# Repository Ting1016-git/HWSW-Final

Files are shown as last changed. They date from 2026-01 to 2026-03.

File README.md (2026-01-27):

# Smart Kitchen Guide

## Project Overview

**Smart Kitchen Guide** is a two-device cooking assistance system designed to help beginners master temperature control in cooking - from Chinese stir-frying to Western pan-searing. The system consists of a **Smart Handle Clip (Sensing Device)** that clamps onto any pan handle and monitors temperatures using triple sensing technology, and a **Cooking Terminal (Display Device)** that provides visual feedback through a stepper motor-driven gauge, LED indicators, and recipe guidance.

The sensing device wirelessly transmits temperature data to the display device, which uses a predictive algorithm to estimate when the target temperature will be reached and alerts the user at the optimal moment to add ingredients.

### Key Features

- **Triple Temperature Sensing**: Pan surface (IR), oil temperature (IR), and food internal temperature (K-type probe)
- **Universal Compatibility**: Spring-clip design fits handles from 15-40mm diameter
- **Open-Pan Cooking**: Perfect for stir-frying and sautéing without blocking the view
- **Wireless BLE Communication**: Real-time data transmission at 10Hz

### General Sketch

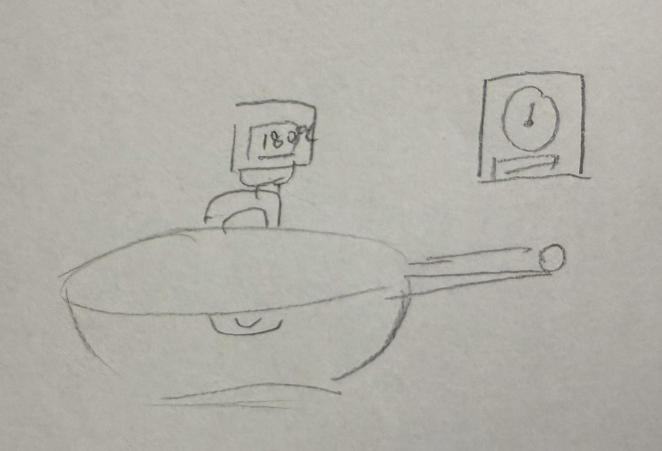
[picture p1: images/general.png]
General System Sketch


**Physical Features:**
- **Smart Handle Clip**: Spring-loaded clamp with OLED display, IR temperature sensor pointing toward pan body, detachable K-type thermocouple probe, and USB-C rechargeable battery
- **Cooking Terminal**: Retro radio-style desktop unit featuring a large circular temperature gauge with stepper motor-driven needle, RGB LED ring, OLED recipe display, and three tactile buttons (Select/Confirm/Back)

---

## Sensing Device: Smart Handle Clip

### Device Description

The Smart Handle Clip is a portable, clip-on temperature monitoring device that attaches to any pan or wok handle. It features **triple temperature sensing capability**:

1. **Infrared (IR) Sensor** - Non-contact measurement of pan surface and oil temperature
2. **K-Type Thermocouple Probe** - Detachable probe for measuring food internal temperature

The clip-on design allows the pan to remain open during cooking, making it ideal for Chinese stir-frying and Western sautéing where visual monitoring is essential.

### Detailed Sketch

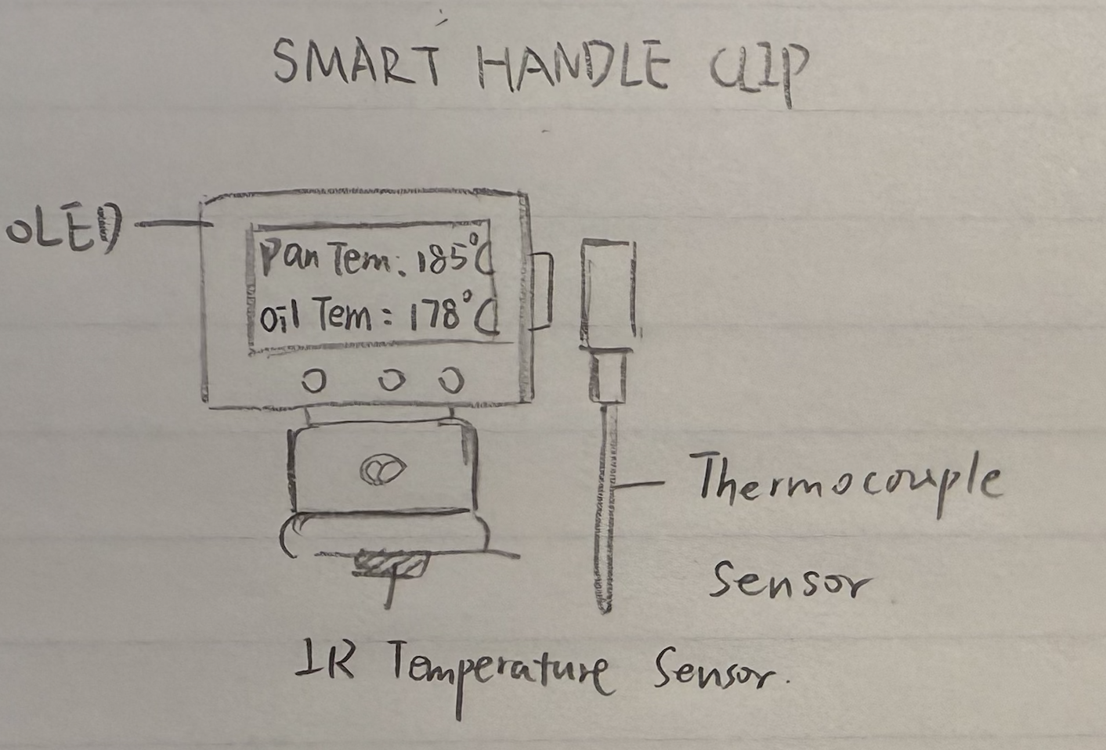
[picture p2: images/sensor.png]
Smart Handle Clip Detailed Sketch


### How It Works

1. **MLX90614 IR sensor** (mounted on bottom jaw, pointing toward pan) measures pan surface temperature from -70°C to +380°C without contact
2. The same IR sensor can measure **oil surface temperature** when the user aims it at the oil (mode switchable via button)
3. **Detachable K-type thermocouple probe** connects via port on the side for measuring food internal temperature (e.g., checking if meat is cooked through)
4. **MAX31855** thermocouple amplifier digitizes the probe signal via SPI
5. **ESP32-C3** microcontroller processes all sensor data at 10Hz and transmits via BLE
6. **0.96" OLED display** shows real-time temperature readings locally
7. **3 Status LEDs** indicate: Green (ready), Yellow (heating), Red (warning/overheat)
8. **500mAh Li-Po battery** provides ~8 hours of operation with USB-C charging

### Components & Part Numbers

| Component | Part Number | Description |
|---|---|---|
| Microcontroller | **ESP32-C3-MINI-1** | WiFi/BLE MCU, low power, SPI/I2C support |
| IR Temperature Sensor | **MLX90614ESF-BAA** | Non-contact IR thermometer, -70°C to +380°C, I2C |
| Thermocouple Sensor | **K-Type Thermocouple Probe** | Detachable, -50°C to +300°C, food-grade stainless steel |
| Thermocouple Amplifier | **MAX31855KASA+T** | Cold-junction compensated, SPI interface |
| OLED Display | **SSD1306 0.96" 128x64** | I2C interface, low power |
| Status LEDs | **0603 SMD LED** | Green, Yellow, Red (x3) |
| Battery | **Li-Po 502535** | 3.7V 500mAh rechargeable |
| Voltage Regulator | **AP2112K-3.3** | 3.3V LDO, 600mA output |
| Charging IC | **TP4056** | 1A Linear Li-ion charger, USB-C |
| Buttons | **TS-1109S** | 6x6mm SMD tact switch (x2: Power, Mode) |

## Display Device: Cooking Terminal

### Device Description

The Cooking Terminal is a desktop unit that receives temperature data from the Smart Handle Clip and provides rich visual feedback. The centerpiece is a large analog-style gauge with a stepper motor-driven needle showing current temperature. An RGB LED ring around the gauge indicates cooking status (heating/ready/overheating), while an OLED screen displays recipe steps and timing information. Users interact via three tactile buttons and can navigate through pre-loaded recipes.

### Detailed Sketch

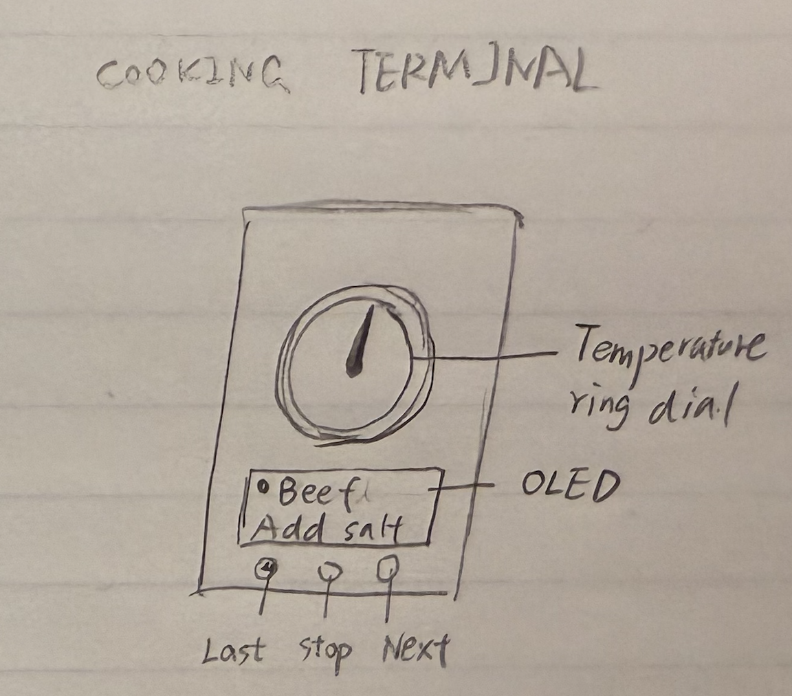
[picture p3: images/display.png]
Cooking Terminal Detailed Sketch


### How It Works

1. The **ESP32-S3** receives temperature data via BLE from the Smart Handle Clip
2. Temperature prediction algorithm estimates time-to-target based on heating rate
3. The **28BYJ-48 stepper motor** drives the gauge needle to indicate current temperature (0-300°C scale)
4. **WS2812B RGB LED ring** shows status: blue (cold), green (heating), amber (target reached), red (overheating)
5. **1.3" OLED display** shows recipe name, current step, target temperature, and countdown timer
6. Three **tactile buttons** allow navigation: Select (◀), Confirm (✓), Back (↩)
7. **Buzzer** provides audio alerts when target temperature is reached
8. Powered by **18650 Li-ion battery** with USB-C charging

### Components & Part Numbers

| Component | Part Number | Description |
|---|---|---|
| Microcontroller | **ESP32-S3-WROOM-1** | Dual-core, BLE 5.0, sufficient GPIO |
| Stepper Motor | **28BYJ-48** | 5V unipolar, 64:1 gear ratio |
| Stepper Driver | **ULN2003A** | Darlington array driver |
| RGB LED Ring | **WS2812B 16-LED Ring** | Addressable RGB, 5V |
| OLED Display | **SH1106 1.3" 128x64** | I2C interface |
| Tactile Buttons | **TS-1109S** | 6x6mm SMD tact switch (x3) |
| Buzzer | **MLT-5020** | 5V active buzzer |
| Battery | **NCR18650B** | 3.7V 3400mAh Li-ion |
| Battery Charger | **TP4056 Module** | USB-C Li-ion charger with protection |
| Voltage Regulator | **AMS1117-3.3** | 3.3V LDO for logic |
| 5V Boost | **MT3608** | Step-up converter for motor/LED |

## System Communication & Architecture

### Communication Diagram

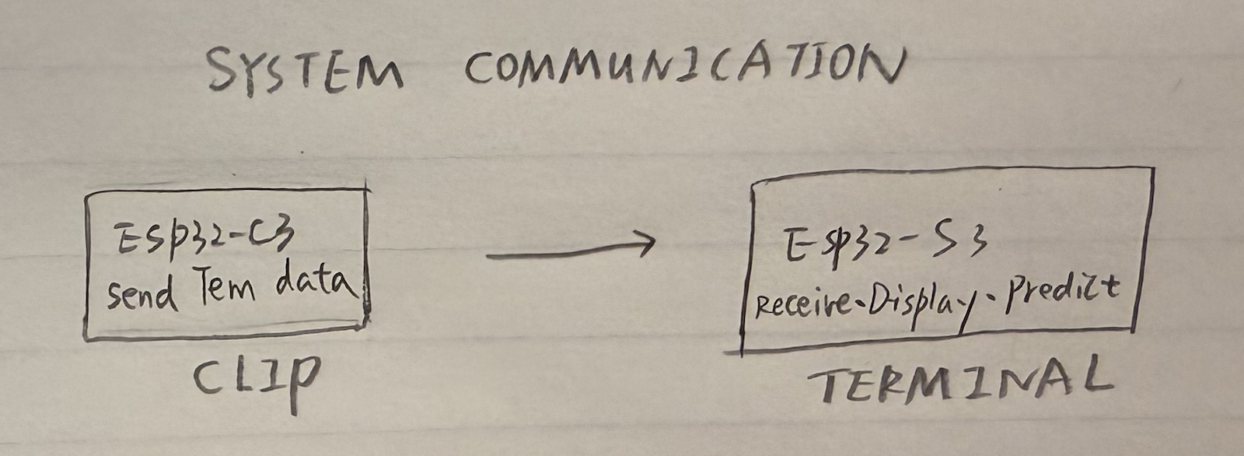
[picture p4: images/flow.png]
Communication Diagram


The Smart Handle Clip and Cooking Terminal communicate via **Bluetooth Low Energy (BLE)**:

- **Protocol**: BLE 5.0 with custom GATT service
- **Update Rate**: 10 Hz (100ms intervals)
- **Range**: Up to 10 meters (typical kitchen environment)
- **Latency**: < 50ms end-to-end

### System Block Diagram

```
┌─────────────────────────────────────────────────────────────────────────────────────┐
│                                 SYSTEM OVERVIEW                                     │
│                                                                                     │
│                                                                                     │
│    ┌──────────────────────┐                         ┌──────────────────────┐        │
│    │                      │                         │                      │        │
│    │   SENSING DEVICE     │      BLE 5.0 Link       │   DISPLAY DEVICE     │        │
│    │  (Smart Handle Clip) │ ═══════════════════════►│  (Cooking Terminal)  │        │
│    │                      │      10Hz, <50ms        │                      │        │
│    │                      │                         │                      │        │
│    └──────────────────────┘                         └──────────────────────┘        │
│                                                                                     │
│                                                                                     │
└─────────────────────────────────────────────────────────────────────────────────────┘
```

---

## Sensing Device (Smart Handle Clip)

```
┌─────────────────────────────────────────────────────────────────────────────────────┐
│                        SMART HANDLE CLIP (Sensing Device)                           │
│                                                                                     │
│                                                                                     │
│    ┌──────────────┐                             ┌──────────────┐                    │
│    │  MLX90614    │                             │ Xiao         │                    │
│    │  IR Sensor   ├──────────────┐      ┌───────┤ ESP32-C3     │                    │
│    │  (I2C)       │              │      │       │ (BLE TX)     │                    │
│    └──────────────┘              │      │       └───────┬──────┘                    │
│                                  │      │               │                           │
│                                  ▼      ▼               │                           │
│                              ┌──────────────┐           │          BLE 5.0          │
│                              │              │           │         ════════►         │
│                              │  Processing  │◄──────────┘                           │
│                              │              │                                       │
│                              └──────┬───────┘                                       │
│                                     │                                               │
│                           ┌─────────┴─────────┐                                     │
│                           │                   │                                     │
│                           ▼                   ▼                                     │
│                    ┌──────────────┐    ┌──────────────┐                             │
│                    │  WS2812B     │    │   Rotary     │                             │
│                    │  RGB LED     │    │   Encoder    │                             │
│                    │  (x1)        │    │   (EC11)     │                             │
│                    └──────────────┘    └──────────────┘                             │
│                                                                                     │
│                                                                                     │
│    ┌──────────────┐         ┌──────────────────────────────────────┐                │
│    │  Li-Po       │         │      Xiao ESP32-C3 Built-in          │                │
│    │  500mAh      ├────────►│  ┌────────────┐    ┌────────────┐    │                │
│    │  3.7V        │         │  │  TP4056    │    │   3.3V     │    │                │
│    └──────────────┘         │  │  Charger   │    │   LDO      │    │                │
│           ▲                 │  └──────┬─────┘    └──────┬─────┘    │                │
│           │                 │         │                 │          │                │
│       USB-C ────────────────┼─────────┘                 └──────────┼───► 3.3V       │
│                             │                                      │                │
│                             └──────────────────────────────────────┘                │
│                                                                                     │
│                                                                                     │
└─────────────────────────────────────────────────────────────────────────────────────┘
```

---

## Display Device (Cooking Terminal)

```
┌─────────────────────────────────────────────────────────────────────────────────────┐
│                        COOKING TERMINAL (Display Device)                            │
│                                                                                     │
│                                              │                                      │
│                                              │ BLE 5.0                              │
│                                              ▼                                      │
│                                      ┌──────────────┐                               │
│                              ┌───────┤ Xiao         │                               │
│                              │       │ ESP32-C3     ├───────┐                       │
│                              │       │ (BLE RX)     │       │                       │
│                              │       └──────────────┘       │                       │
│                              │               │              │                       │
│                              │               │              │                       │
│      ┌───────────────────────┼───────────────┼──────────────┼───────────────┐       │
│      │                       │               │              │               │       │
│      ▼                       ▼               ▼              ▼               ▼       │
│ ┌──────────┐ ┌──────────┐ ┌──────────┐ ┌──────────┐ ┌──────────┐ ┌──────────┐       │
│ │ ULN2003A │ │ WS2812B  │ │ SH1106   │ │ Rotary   │ │ Piezo    │ │ Temp     │       │
│ │ Driver   │ │ RGB Ring │ │ OLED     │ │ Encoder  │ │ Buzzer   │ │ Predict  │       │
│ │          │ │ (x8)     │ │ 1.3"     │ │ (EC11)   │ │          │ │ Algo     │       │
│ └────┬─────┘ └──────────┘ └──────────┘ └──────────┘ └──────────┘ └──────────┘       │
│      │                                                                              │
│      ▼                                                                              │
│ ┌──────────┐                                                                        │
│ │ 28BYJ-48 │                                                                        │
│ │ Stepper  │                                                                        │
│ │ Motor    │                                                                        │
│ └────┬─────┘                                                                        │
│      │                                                                              │
│      ▼                                                                              │
│ ┌──────────┐                                                                        │
│ │ Gauge    │                                                                        │
│ │ Needle   │                                                                        │
│ └──────────┘                                                                        │
│                                                                                     │
│                                                                                     │
│    ┌──────────────┐       ┌──────────────┐                                          │
│    │  18650       │       │   TP4056     │◄──── USB-C                               │
│    │  Battery     ├──────►│   Charger    │                                          │
│    │  3400mAh     │       │   (Xiao)     │                                          │
│    └──────────────┘       └───────┬──────┘                                          │
│                                   │                                                 │
│                    ┌──────────────┴──────────────┐                                  │
│                    │                             │                                  │
│                    ▼                             ▼                                  │
│            ┌──────────────┐             ┌──────────────┐                            │
│            │  Xiao 3.3V   │             │   MT3608     │                            │
│            │  LDO         │             │   Boost      │                            │
│            └───────┬──────┘             └───────┬──────┘                            │
│                    │                            │                                   │
│                    ▼                            ▼                                   │
│              3.3V (Logic)                 5V (Motor/LED)                            │
│              • Xiao MCU                   • ULN2003A                                │
│              • SH1106 OLED                • 28BYJ-48                                │
│              • Rotary Encoder             • WS2812B                                 │
│                                           • Piezo Buzzer                            │
│                                                                                     │
└─────────────────────────────────────────────────────────────────────────────────────┘
```

---

## Complete System Block Diagram

```
┌─────────────────────────────────────────────────────────────────────────────────────┐
│                        SMART HANDLE CLIP (Sensing Device)                           │
│                                                                                     │
│    ┌──────────────┐              ┌──────────────┐        ┌──────────────┐           │
│    │  MLX90614    │    I2C       │              │        │  WS2812B     │           │
│    │  IR Sensor   ├─────────────►│ Xiao         │◄───────┤  RGB LED     │           │
│    └──────────────┘              │ ESP32-C3     │        │  (x1)        │           │
│                                  │              │        └──────────────┘           │
│    ┌──────────────┐    GPIO      │ (BLE TX)     │        ┌──────────────┐           │
│    │  Rotary      ├─────────────►│              │        │  Li-Po       │           │
│    │  Encoder     │              └───────┬──────┘        │  500mAh      │           │
│    └──────────────┘                      │               └───────┬──────┘           │
│                                          │                       │                  │
│                                          │ BLE 5.0               │ Power            │
│                                          │                       ▼                  │
│                                          │               ┌──────────────┐           │
│                                          │               │ Xiao Built-in│           │
│                                          │               │ Charger+LDO  │◄── USB-C  │
│                                          │               └──────────────┘           │
│                                          │                       │                  │
│                                          │                       ▼                  │
│                                          │                    3.3V Out              │
└──────────────────────────────────────────┼──────────────────────────────────────────┘
                                           │
                                           │
                        ═══════════════════╪═══════════════════
                              Wireless     │     Communication
                        ═══════════════════╪═══════════════════
                                           │
                                           │
┌──────────────────────────────────────────┼──────────────────────────────────────────┐
│                        COOKING TERMINAL (Display Device)                            │
│                                          │                                          │
│                                          ▼                                          │
│    ┌──────────────────────────────────────────────────────────────────────────┐     │
│    │                            Xiao ESP32-C3                                 │     │
│    │                              (BLE RX)                                    │     │
│    │                                                                          │     │
│    │    ┌──────────────┐                                                      │     │
│    │    │    Temp      │                                                      │     │
│    │    │   Predict    │                                                      │     │
│    │    │    Algo      │                                                      │     │
│    │    └──────────────┘                                                      │     │
│    │                                                                          │     │
│    └───┬────────┬────────┬────────┬────────┬────────┬─────────────────────────┘     │
│        │        │        │        │        │        │                               │
│        ▼        ▼        ▼        ▼        ▼        ▼                               │
│   ┌────────┐┌────────┐┌────────┐┌────────┐┌────────┐┌────────┐                      │
│   │ULN2003A││WS2812B ││SH1106  ││Rotary  ││Piezo   ││        │                      │
│   │ Driver ││RGB Ring││OLED    ││Encoder ││Buzzer  ││        │                      │
│   └───┬────┘│ (x8)   ││ 1.3"   │└────────┘└────────┘│        │                      │
│       │     └────────┘└────────┘                    │        │                      │
│       ▼                                             │        │                      │
│   ┌────────┐                                        │        │                      │
│   │28BYJ-48│                                        │        │                      │
│   │Stepper │                                        │        │                      │
│   │ Motor  │                                        │        │                      │
│   └───┬────┘                                        │        │                      │
│       │                                             │        │                      │
│       ▼                                             │        │                      │
│   ┌────────┐                                        │        │                      │
│   │ Gauge  │                                        │        │                      │
│   │ Needle │                                        │        │                      │
│   └────────┘                                        │        │                      │
│                                                     │        │                      │
│                                                     │        │                      │
│    ┌──────────────┐      ┌──────────────┐           │        │                      │
│    │   18650      │      │   Xiao       │◄── USB-C  │        │                      │
│    │   Battery    ├─────►│   Charger    │           │        │                      │
│    │   3400mAh    │      └───────┬──────┘           │        │                      │
│    └──────────────┘              │                  │        │                      │
│                                  │                  │        │                      │
│                    ┌─────────────┴─────────────┐    │        │                      │
│                    │                           │    │        │                      │
│                    ▼                           ▼    │        │                      │
│            ┌──────────────┐            ┌──────────────┐      │                      │
│            │    3.3V      │            │   MT3608     │      │                      │
│            │    LDO       │            │   5V Boost   │      │                      │
│            └───────┬──────┘            └───────┬──────┘      │                      │
│                    │                           │             │                      │
│                    ▼                           ▼             │                      │
│               3.3V (Logic)                5V (Motor/LED)     │                      │
│                                                              │                      │
└─────────────────────────────────────────────────────────────────────────────────────┘
```

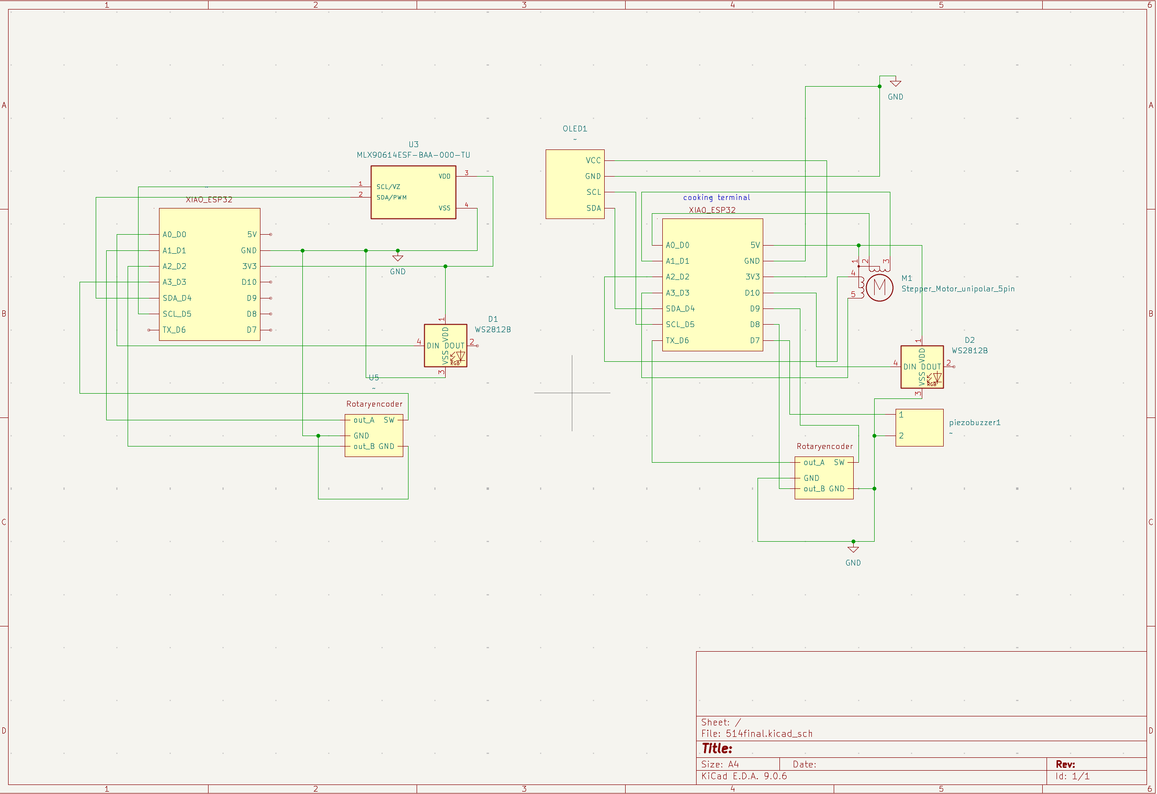
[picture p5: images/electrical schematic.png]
electrical schematic


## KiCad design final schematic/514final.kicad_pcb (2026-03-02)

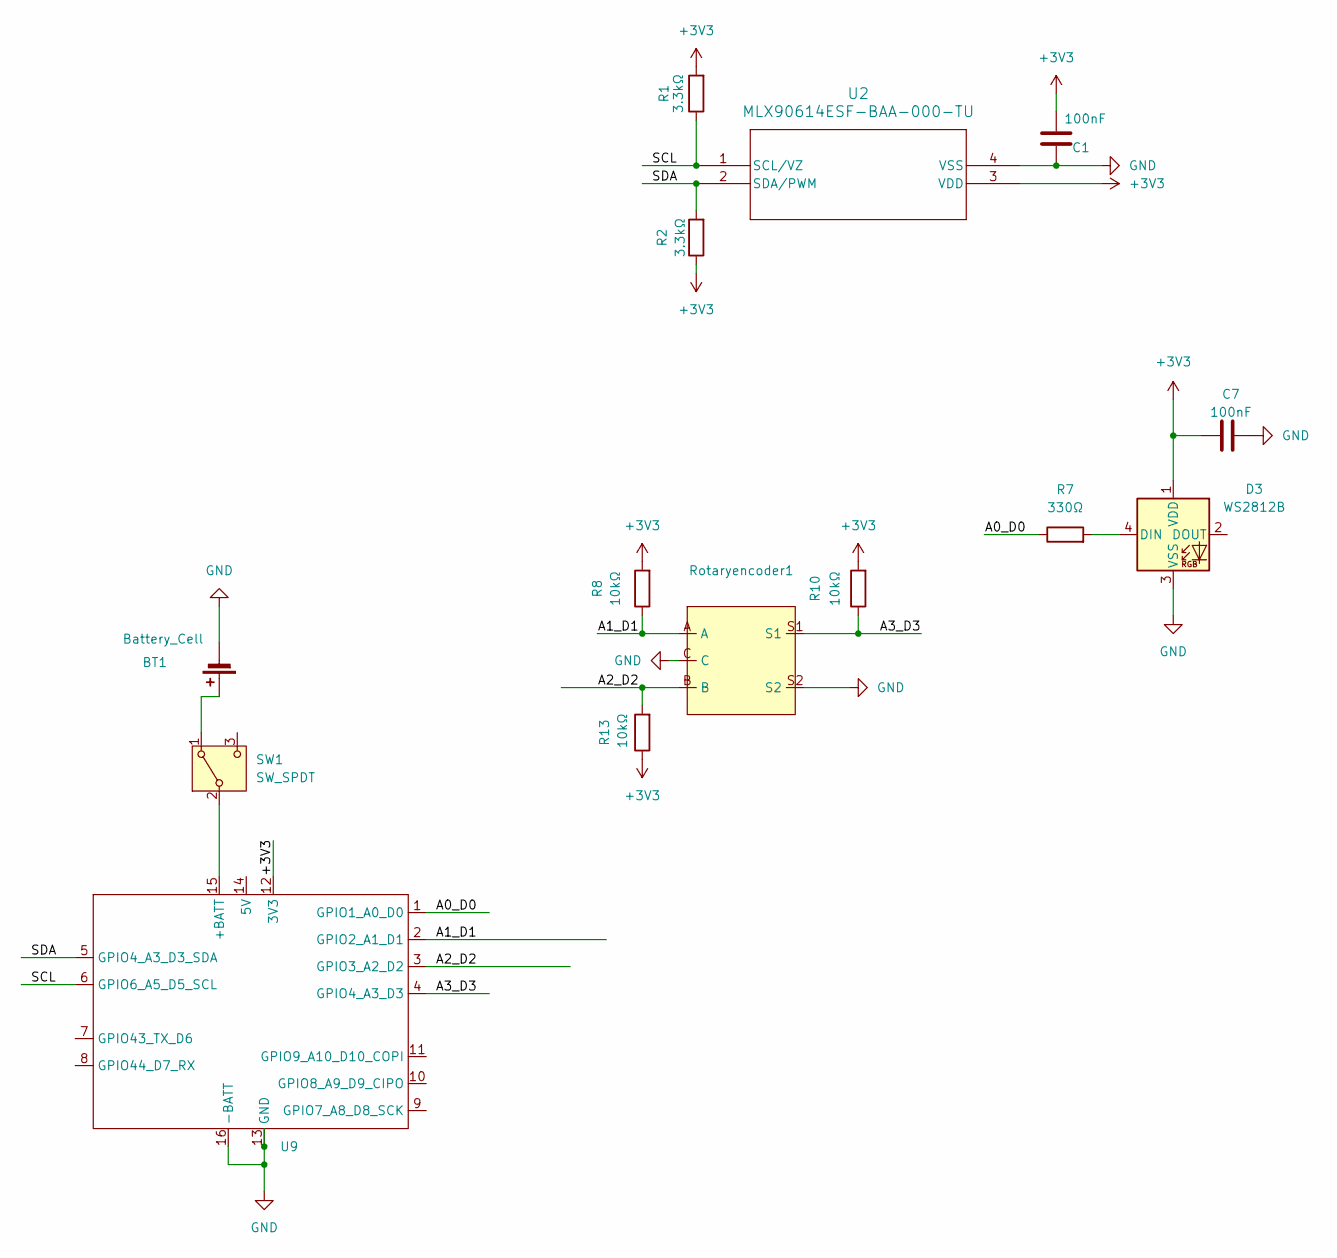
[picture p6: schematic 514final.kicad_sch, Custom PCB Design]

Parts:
BT1: Battery_Cell; PinSocket_1x02_P2.54mm_Vertical
C1, C7: 100nF; C_0603_1608Metric_Pad1.08x0.95mm_HandSolder
D3: WS2812B; LED_WS2812B_PLCC4_5.0x5.0mm_P3.2mm
R1, R2: 3.3kΩ; R_0603_1608Metric_Pad0.98x0.95mm_HandSolder
R7: 330Ω; R_0603_1608Metric_Pad0.98x0.95mm_HandSolder
R8, R10, R13: 10kΩ; R_0603_1608Metric_Pad0.98x0.95mm_HandSolder
Rotaryencoder1: RotaryEncoder_Alps_EC11E-Switch_Vertical_H20mm_CircularMoun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
SW1: SW_SPDT; PinSocket_1x03_P2.54mm_Vertical
U2: MLX90614ESF-BAA-000-TU; MLX90614ESF-BAA_MEL
U9: XIAO_ESP32

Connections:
+3V3: C1.1, C7.1, D3.1 (VDD), R1.2, R2.1, R8.2, R10.2, R13.1, U2.3 (VDD), U9.12 (3V3)
/A0_D0: R7.1, U9.1 (GPIO1_A0_D0)
/A1_D1: R8.1, Rotaryencoder1.A, U9.2 (GPIO2_A1_D1)
/A2_D2: R13.2, Rotaryencoder1.B, U9.3 (GPIO3_A2_D2)
/A3_D3: R10.1, Rotaryencoder1.S1, U9.4 (GPIO4_A3_D3)
/SCL: R1.1, U2.1 (SCL/VZ), U9.6 (GPIO6_A5_D5_SCL)
/SDA: R2.2, U2.2 (SDA/PWM), U9.5 (GPIO4_A3_D3_SDA)
GND: BT1.2 (-), C1.2, C7.2, D3.3 (VSS), Rotaryencoder1.C, Rotaryencoder1.S2, U2.4 (VSS), U9.13 (GND), U9.16 (-BATT)
unnamed: BT1.1 (+), SW1.1 (A)
unnamed: D3.4 (DIN), R7.2
unnamed: SW1.2 (B), U9.15 (+BATT)

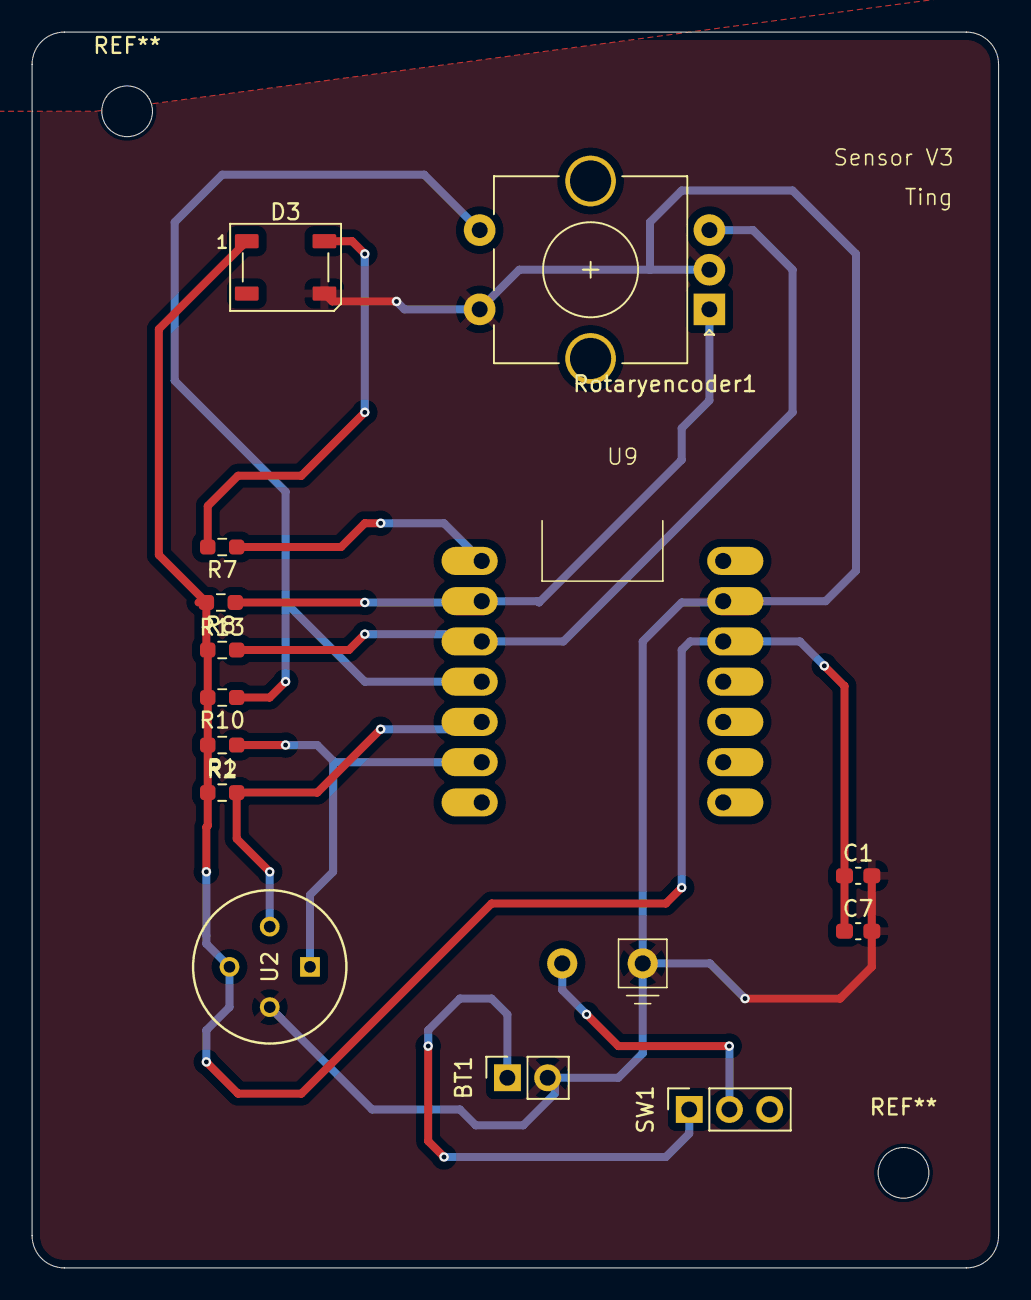
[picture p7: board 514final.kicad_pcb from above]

Board: 2 copper layers, 61.0 x 78.0 mm, 14 parts (0 on the bottom side), 11 nets.

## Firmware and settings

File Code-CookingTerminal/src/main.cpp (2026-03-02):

/*
 * Cooking Terminal - Smart Kitchen Guide
 * Version: 2.0 (Fixed & Complete)
 * 
 * Hardware:
 * - Xiao ESP32-C3 (Main MCU)
 * - SH1106 OLED 1.3" (I2C)
 * - X27.168 Stepper Motor (4-pin, direct GPIO)
 * - WS2812B RGB LED (1 LED)
 * - EC11 Rotary Encoder (5-pin)
 * - Piezo Buzzer (2-pin)
 * 
 * Pin Assignment:
 * - D0  (GPIO2)  -> X27.168 Pin 1 (Coil A+)
 * - D1  (GPIO3)  -> X27.168 Pin 2 (Coil A-)
 * - D2  (GPIO4)  -> X27.168 Pin 3 (Coil B+)
 * - D3  (GPIO5)  -> WS2812B DIN
 * - D4  (GPIO6)  -> OLED SDA
 * - D5  (GPIO7)  -> OLED SCL
 * - D6  (GPIO21) -> Encoder OUT_A
 * - D7  (GPIO20) -> Buzzer (+)
 * - D8  (GPIO8)  -> Encoder OUT_B
 * - D9  (GPIO9)  -> Encoder SW
 * - D10 (GPIO10) -> X27.168 Pin 4 (Coil B-)
 * 
 * Features:
 * - Temperature gauge display (0-300°C)
 * - OLED display with current/target temp
 * - Rotary encoder for target temp adjustment
 * - LED color status indicator
 * - Buzzer alerts when target reached
 */

#include <Arduino.h>
#include <Wire.h>
#include <Adafruit_GFX.h>
#include <Adafruit_SH110X.h>
#include <Adafruit_NeoPixel.h>

// ============== Pin Definitions ==============
// X27.168 Stepper Motor (4-pin)
#define STEPPER_PIN1  2    // D0 - GPIO2 - Coil A+
#define STEPPER_PIN2  3    // D1 - GPIO3 - Coil A-
#define STEPPER_PIN3  4    // D2 - GPIO4 - Coil B+
#define STEPPER_PIN4  10   // D10 - GPIO10 - Coil B-

// WS2812B LED
#define LED_PIN       5    // D3 - GPIO5
#define LED_COUNT     1

// OLED Display (I2C)
#define OLED_SDA      6    // D4 - GPIO6
#define OLED_SCL      7    // D5 - GPIO7

// Rotary Encoder
#define ENCODER_A     21   // D6 - GPIO21
#define ENCODER_B     8    // D8 - GPIO8
#define ENCODER_SW    9    // D9 - GPIO9

// Buzzer
#define BUZZER_PIN    20   // D7 - GPIO20

// ============== Objects ==============
Adafruit_SH1106G oled(128, 64, &Wire, -1);
Adafruit_NeoPixel led(LED_COUNT, LED_PIN, NEO_GRB + NEO_KHZ800);

// ============== Function Prototypes ==============
void stepMotor(int step);
void homeStepper();
void updateStepper();
void readEncoder();
void checkButton();
void simulateTemperature();
void updateLED();
void beep(int duration);
void alertBeep();
void updateDisplay();
void checkTargetReached();

// ============== Variables ==============
// Stepper motor
int currentStep = 0;
int targetStep = 0;
const int STEPS_PER_REV = 600;    // X27.168 steps per revolution
const int MAX_STEPS = 450;         // 270 degrees (3/4 of 600)
unsigned long lastStepTime = 0;
const int STEP_DELAY_US = 1500;    // Microseconds between steps

// Encoder
volatile int encoderPos = 0;
int lastEncoderA = HIGH;
int lastEncoderB = HIGH;
bool buttonPressed = false;
unsigned long lastButtonTime = 0;
const int DEBOUNCE_DELAY = 200;

// Temperature
float currentTemp = 25.0;          // Current measured temperature
float targetTemp = 150.0;          // User-set target temperature
bool targetReached = false;        // Flag for target reached alert
bool alertPlayed = false;          // Flag to prevent repeated alerts

// Display update
unsigned long lastDisplayUpdate = 0;
const int DISPLAY_UPDATE_INTERVAL = 100;  // ms

// Stepper sequence for X27.168 (modified for correct rotation)
const int stepSequence[4][4] = {
  {1, 0, 0, 1},  // Step 0
  {1, 0, 1, 0},  // Step 1
  {0, 1, 1, 0},  // Step 2
  {0, 1, 0, 1}   // Step 3
};

// ============== Setup ==============
void setup() {
  Serial.begin(115200);
  delay(1000);
  Serial.println("\n================================");
  Serial.println("Cooking Terminal v2.0 Starting...");
  Serial.println("================================\n");

  // Initialize I2C for OLED
  Wire.begin(OLED_SDA, OLED_SCL);
  Serial.println("[INIT] I2C initialized");
  
  // Initialize OLED
  Serial.print("[INIT] OLED... ");
  if (!oled.begin(0x3C, true)) {
    Serial.println("FAILED! Check wiring.");
  } else {
    Serial.println("OK");
    oled.clearDisplay();
    oled.setTextSize(1);
    oled.setTextColor(SH110X_WHITE);
    oled.setCursor(20, 20);
    oled.println("Cooking Terminal");
    oled.setCursor(35, 35);
    oled.println("Starting...");
    oled.display();
  }

  // Initialize LED
  Serial.print("[INIT] LED... ");
  led.begin();
  led.setBrightness(50);
  led.setPixelColor(0, led.Color(0, 0, 255));  // Blue during startup
  led.show();
  Serial.println("OK");

  // Initialize Stepper pins
  Serial.print("[INIT] Stepper... ");
  pinMode(STEPPER_PIN1, OUTPUT);
  pinMode(STEPPER_PIN2, OUTPUT);
  pinMode(STEPPER_PIN3, OUTPUT);
  pinMode(STEPPER_PIN4, OUTPUT);
  digitalWrite(STEPPER_PIN1, LOW);
  digitalWrite(STEPPER_PIN2, LOW);
  digitalWrite(STEPPER_PIN3, LOW);
  digitalWrite(STEPPER_PIN4, LOW);
  Serial.println("OK");

  // Initialize Encoder pins
  Serial.print("[INIT] Encoder... ");
  pinMode(ENCODER_A, INPUT_PULLUP);
  pinMode(ENCODER_B, INPUT_PULLUP);
  pinMode(ENCODER_SW, INPUT_PULLUP);
  lastEncoderA = digitalRead(ENCODER_A);
  lastEncoderB = digitalRead(ENCODER_B);
  Serial.println("OK");

  // Initialize Buzzer
  Serial.print("[INIT] Buzzer... ");
  pinMode(BUZZER_PIN, OUTPUT);
  digitalWrite(BUZZER_PIN, LOW);
  Serial.println("OK");
  
  // Startup beeps
  beep(100);
  delay(100);
  beep(100);
  delay(100);
  beep(200);

  // Home the stepper
  Serial.println("[INIT] Homing stepper...");
  homeStepper();
  Serial.println("[INIT] Stepper homed");

  // Set LED to green (ready)
  led.setPixelColor(0, led.Color(0, 255, 0));
  led.show();

  Serial.println("\n================================");
  Serial.println("System Ready!");
  Serial.println("================================");
  Serial.println("Controls:");
  Serial.println("  Rotate encoder: Adjust target temp");
  Serial.println("  Press button: Reset to 25C");
  Serial.println("================================\n");
  
  delay(500);
}

// ============== Main Loop ==============
void loop() {
  readEncoder();
  checkButton();
  simulateTemperature();
  checkTargetReached();
  updateLED();
  updateStepper();
  
  if (millis() - lastDisplayUpdate >= DISPLAY_UPDATE_INTERVAL) {
    updateDisplay();
    lastDisplayUpdate = millis();
  }
  
  delay(1);
}

// ============== Stepper Functions ==============
void stepMotor(int step) {
  int idx = step % 4;
  if (idx < 0) idx += 4;
  
  digitalWrite(STEPPER_PIN1, stepSequence[idx][0]);
  digitalWrite(STEPPER_PIN2, stepSequence[idx][1]);
  digitalWrite(STEPPER_PIN3, stepSequence[idx][2]);
  digitalWrite(STEPPER_PIN4, stepSequence[idx][3]);
}

void homeStepper() {
  Serial.println("  Sweeping forward...");
  for (int i = 0; i <= 100; i++) {
    stepMotor(i);
    delay(3);
  }
  
  Serial.println("  Sweeping back to zero...");
  for (int i = 100; i >= 0; i--) {
    stepMotor(i);
    delay(3);
  }
  
  digitalWrite(STEPPER_PIN1, LOW);
  digitalWrite(STEPPER_PIN2, LOW);
  digitalWrite(STEPPER_PIN3, LOW);
  digitalWrite(STEPPER_PIN4, LOW);
  
  currentStep = 0;
}

void updateStepper() {
  targetStep = (int)((currentTemp / 300.0) * MAX_STEPS);
  targetStep = constrain(targetStep, 0, MAX_STEPS);
  
  if (micros() - lastStepTime >= STEP_DELAY_US) {
    if (currentStep < targetStep) {
      currentStep++;
      stepMotor(currentStep);
      lastStepTime = micros();
    } else if (currentStep > targetStep) {
      currentStep--;
      stepMotor(currentStep);
      lastStepTime = micros();
    }
  }
}

// ============== Encoder Functions ==============
void readEncoder() {
  int currentA = digitalRead(ENCODER_A);
  int currentB = digitalRead(ENCODER_B);
  
  if (currentA != lastEncoderA && currentA == LOW) {
    if (currentB == HIGH) {
      encoderPos++;
      targetTemp += 5.0;
      beep(10);
    } else {
      encoderPos--;
      targetTemp -= 5.0;
      beep(10);
    }
    
    targetTemp = constrain(targetTemp, 0.0, 300.0);
    alertPlayed = false;
    
    Serial.print("[ENCODER] Target: ");
    Serial.print(targetTemp);
    Serial.println(" C");
  }
  
  lastEncoderA = currentA;
  lastEncoderB = currentB;
}

void checkButton() {
  if (digitalRead(ENCODER_SW) == LOW) {
    if (millis() - lastButtonTime > DEBOUNCE_DELAY) {
      buttonPressed = true;
      lastButtonTime = millis();
      
      currentTemp = 25.0;
      alertPlayed = false;
      
      Serial.println("[BUTTON] Reset to 25C");
      
      beep(50);
      delay(50);
      beep(50);
    }
  }
}

// ============== Temperature Functions ==============
void simulateTemperature() {
  static unsigned long lastSimUpdate = 0;
  const int SIM_INTERVAL = 100;
  
  if (millis() - lastSimUpdate >= SIM_INTERVAL) {
    if (currentTemp < targetTemp - 0.5) {
      currentTemp += 0.3;
    } else if (currentTemp > targetTemp + 0.5) {
      currentTemp -= 0.3;
    }
    lastSimUpdate = millis();
  }
}

void checkTargetReached() {
  if (abs(currentTemp - targetTemp) < 5.0 && !alertPlayed) {
    Serial.println("[ALERT] Target temperature reached!");
    alertBeep();
    alertPlayed = true;
  }
}

// ============== LED Functions ==============
void updateLED() {
  uint32_t color;
  
  if (currentTemp >= 250) {
    static bool flashState = false;
    static unsigned long lastFlash = 0;
    if (millis() - lastFlash > 200) {
      flashState = !flashState;
      lastFlash = millis();
    }
    color = flashState ? led.Color(255, 0, 0) : led.Color(0, 0, 0);
  } else if (currentTemp >= 200) {
    color = led.Color(255, 0, 0);       // Red
  } else if (currentTemp >= 150) {
    color = led.Color(255, 200, 0);     // Yellow
  } else if (currentTemp >= 100) {
    color = led.Color(255, 100, 0);     // Orange
  } else if (currentTemp >= 50) {
    color = led.Color(100, 255, 0);     // Light green
  } else {
    color = led.Color(0, 255, 0);       // Green
  }
  
  led.setPixelColor(0, color);
  led.show();
}

// ============== Buzzer Functions ==============
void beep(int duration) {
  digitalWrite(BUZZER_PIN, HIGH);
  delay(duration);
  digitalWrite(BUZZER_PIN, LOW);
}

void alertBeep() {
  for (int i = 0; i < 3; i++) {
    beep(150);
    delay(100);
  }
}

// ============== Display Functions ==============
void updateDisplay() {
  oled.clearDisplay();
  
  // Title
  oled.setTextSize(1);
  oled.setCursor(0, 0);
  oled.print("Cooking Terminal");
  oled.drawLine(0, 10, 128, 10, SH110X_WHITE);
  
  // Current Temperature
  oled.setTextSize(2);
  oled.setCursor(0, 14);
  oled.print(currentTemp, 1);
  oled.setTextSize(1);
  oled.print(" C");
  
  // Temperature bar
  int barWidth = map((int)currentTemp, 0, 300, 0, 100);
  barWidth = constrain(barWidth, 0, 100);
  oled.drawRect(0, 32, 102, 8, SH110X_WHITE);
  oled.fillRect(1, 33, barWidth, 6, SH110X_WHITE);
  
  // Target marker on bar
  int targetX = map((int)targetTemp, 0, 300, 0, 100);
  targetX = constrain(targetX, 0, 100);
  oled.drawLine(targetX, 30, targetX, 42, SH110X_WHITE);
  
  // Target Temperature
  oled.setTextSize(1);
  oled.setCursor(0, 44);
  oled.print("Target: ");
  oled.print(targetTemp, 0);
  oled.print(" C");
  
  // Status
  oled.setCursor(0, 55);
  if (currentTemp >= 250) {
    oled.print("!! DANGER !!");
  } else if (currentTemp >= 200) {
    oled.print("Status: VERY HOT");
  } else if (abs(currentTemp - targetTemp) < 5.0) {
    oled.print("Status: READY!");
  } else if (currentTemp < targetTemp) {
    oled.print("Status: Heating...");
  } else {
    oled.print("Status: Cooling...");
  }
  
  oled.display();
}

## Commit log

2026-01-27 update architecture
    [514final.kicad_sch]
2026-01-30 finish pcb design
    [TECHIN514-Lab3-BOM.csv, TECHIN514-Lab3.kicad_pcb, TECHIN514-Lab3.kicad_sch]
2026-02-07 update battery and datasheet link
    [514final.kicad_pcb, 514final.kicad_sch, TECHIN514-Lab3-BOM.csv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]
2026-03-02 add second device code
    [514final.kicad_pcb, 514final.kicad_sch, display device.xlsx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]
